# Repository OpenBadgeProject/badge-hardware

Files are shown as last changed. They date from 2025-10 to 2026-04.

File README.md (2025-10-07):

# Open Badge Project - Surface Mount Version

This is the Open Badge Project hardware repository.

There are two badge designs in this repo. The surface-mount directory holds the surface mount badge design. The production subdirectory contains the BOM and position data files.

The through-hole directory is for the through hole badge material. There is no BOM or pick and place spreadsheet. There's no reason you couldn't do that, but it was designed for humans to solder.

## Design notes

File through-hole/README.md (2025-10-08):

# Through Hole Badge design files

The programmer directory has a 3d model for a programmer that uses pogo pins connected to an arduino for programming

## Parts List
You can generate a bill of materials from KiCad, but for the sake of simplicity here is a list of all the parts.

- 1 [ATTINY85](https://www.digikey.com/en/products/detail/microchip-technology/ATTINY85-20PU/735469)
- 1 PCB (you have to get this made, you can't buy them)
- 2 [CD74HC595E](https://www.digikey.com/en/products/detail/texas-instruments/CD74HC595E/1507396) shift registers
- 1 [CD4021BE](https://www.digikey.com/en/products/detail/texas-instruments/CD4021BE/67261) shift register
- 1 [2032 battery holder](https://www.digikey.com/en/products/detail/adam-tech/BH-25C-1/13537703)
- 8 [100 Ohm resistors](https://www.digikey.com/en/products/detail/stackpole-electronics-inc/CF14JT100R/1741261)
- 8 [100K Ohm resistors](https://www.digikey.com/en/products/detail/stackpole-electronics-inc/CF14JT10K0/1741265)
- 6 [Buttons](https://www.amazon.com/gp/product/B07VSNN9S2/ref=ppx_yo_dt_b_asin_title_o00_s00?ie=UTF8&th=1)
- 1 [8x8 LED Display](https://www.aliexpress.us/item/3256805713726832.html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)

There may be better places to purchase these things than these links. Please submit a PR if you find something better.

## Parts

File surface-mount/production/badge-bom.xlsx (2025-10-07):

Comment | Designator | Footprint | LCSC Part Number
 | BAT1 | Battery:BatteryHolder_MPD_BC2003_1x2032 | C964831
 | D29,D8,D15,D52,D61,D27,D35,D1,D4,D26,D60,D3,D63,D20,D48,D10,D11,D49,D58,D40,D34,D17,D31,D36,D23,D2,D38,D24,D54,D57,D28,D42,D64,D55,D9,D16,D39,D53,D18,D19,D43,D62,D51,D56,D5,D33,D37,D50,D30,D13,D47,D41,D21,D22,D14,D59,D6,D12,D7,D46,D44,D32,D25,D45 | LED_SMD:LED_1206_3216Metric_Pad1.42x1.75mm_HandSolder | C84270
100 | R1,R3,R6,R5,R2,R7,R4,R8 | PCM_JLCPCB:R_0805 | C702858
10K | R15,R14,R11,R9,R10,R16,R13,R12 | PCM_JLCPCB:R_0805 | C17414
 | S1,S2,S3,S4,S5,S6 | Badge-Library:C83206,Button_Switch_SMD:SW_MEC_5GSH9 | C83206
 | U1 | Package_SO:SOIC-8_5.3x5.3mm_P1.27mm | C615549
 | U2 | PCM_JLCPCB:SOIC-16_L9.9-W3.9-P1.27-LS6.0-BL | C134120
 | U4,U3 | PCM_JLCPCB:SOIC-16_L9.9-W3.9-P1.27-LS6.0-BL | C5947

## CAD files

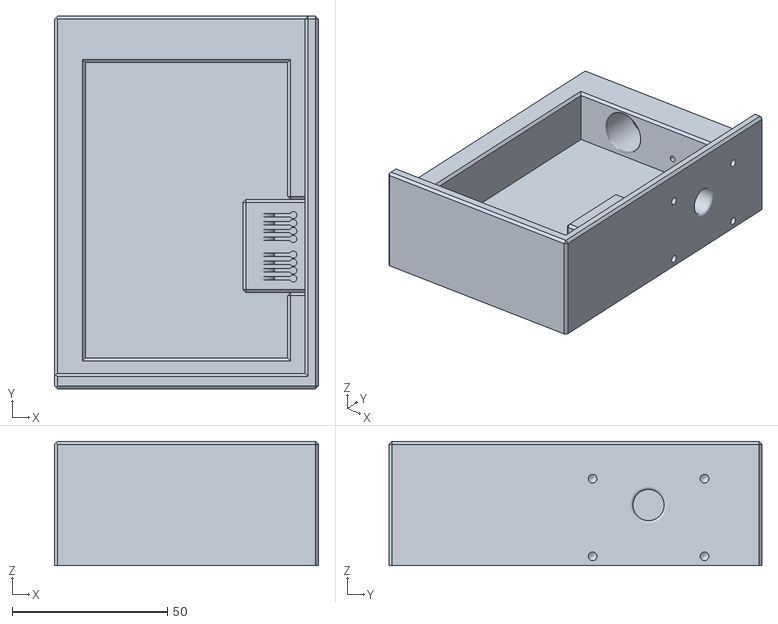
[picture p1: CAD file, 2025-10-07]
surface-mount/programmer/surface-mount-programmer.stl
85.0 x 120.0 x 40.0

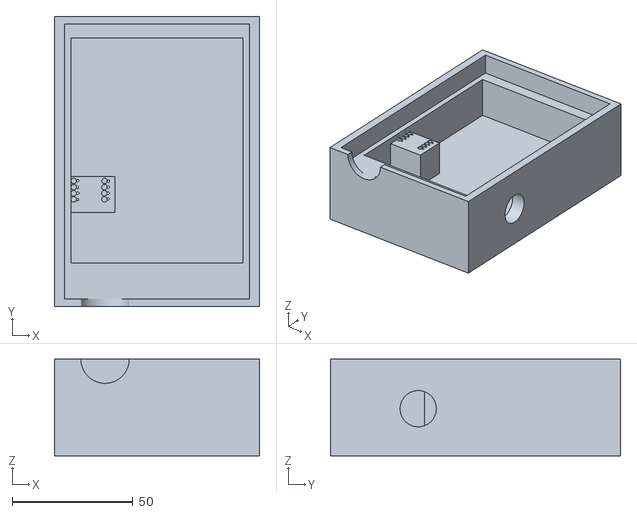
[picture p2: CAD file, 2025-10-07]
through-hole/programmer/through-hole-programmer.stl
85.0 x 120.0 x 40.0

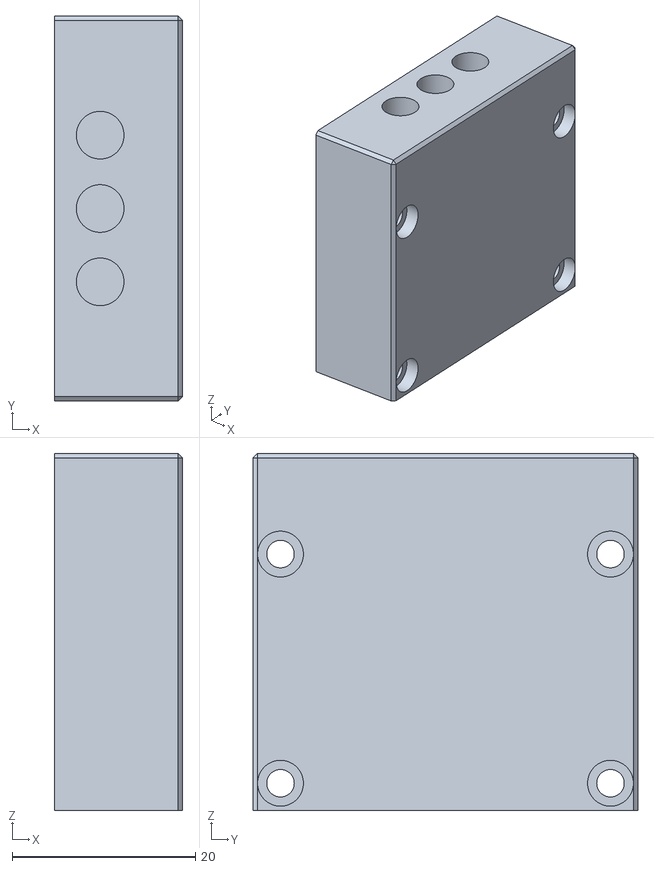
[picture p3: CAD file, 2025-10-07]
surface-mount/programmer/LED-holder.stl
14.0 x 42.0 x 39.0

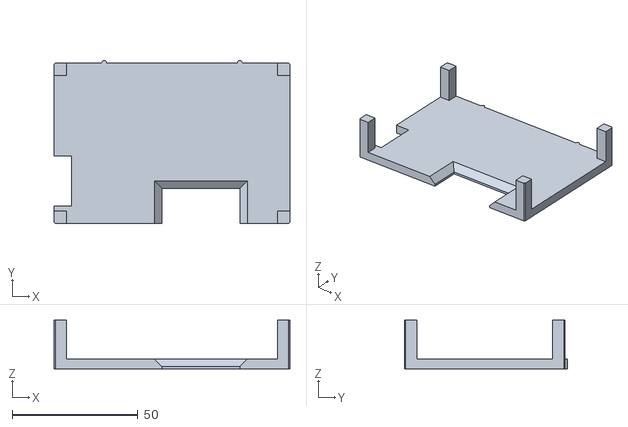
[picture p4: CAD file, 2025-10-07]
surface-mount/programmer/lid.stl
94.0 x 65.0 x 19.5

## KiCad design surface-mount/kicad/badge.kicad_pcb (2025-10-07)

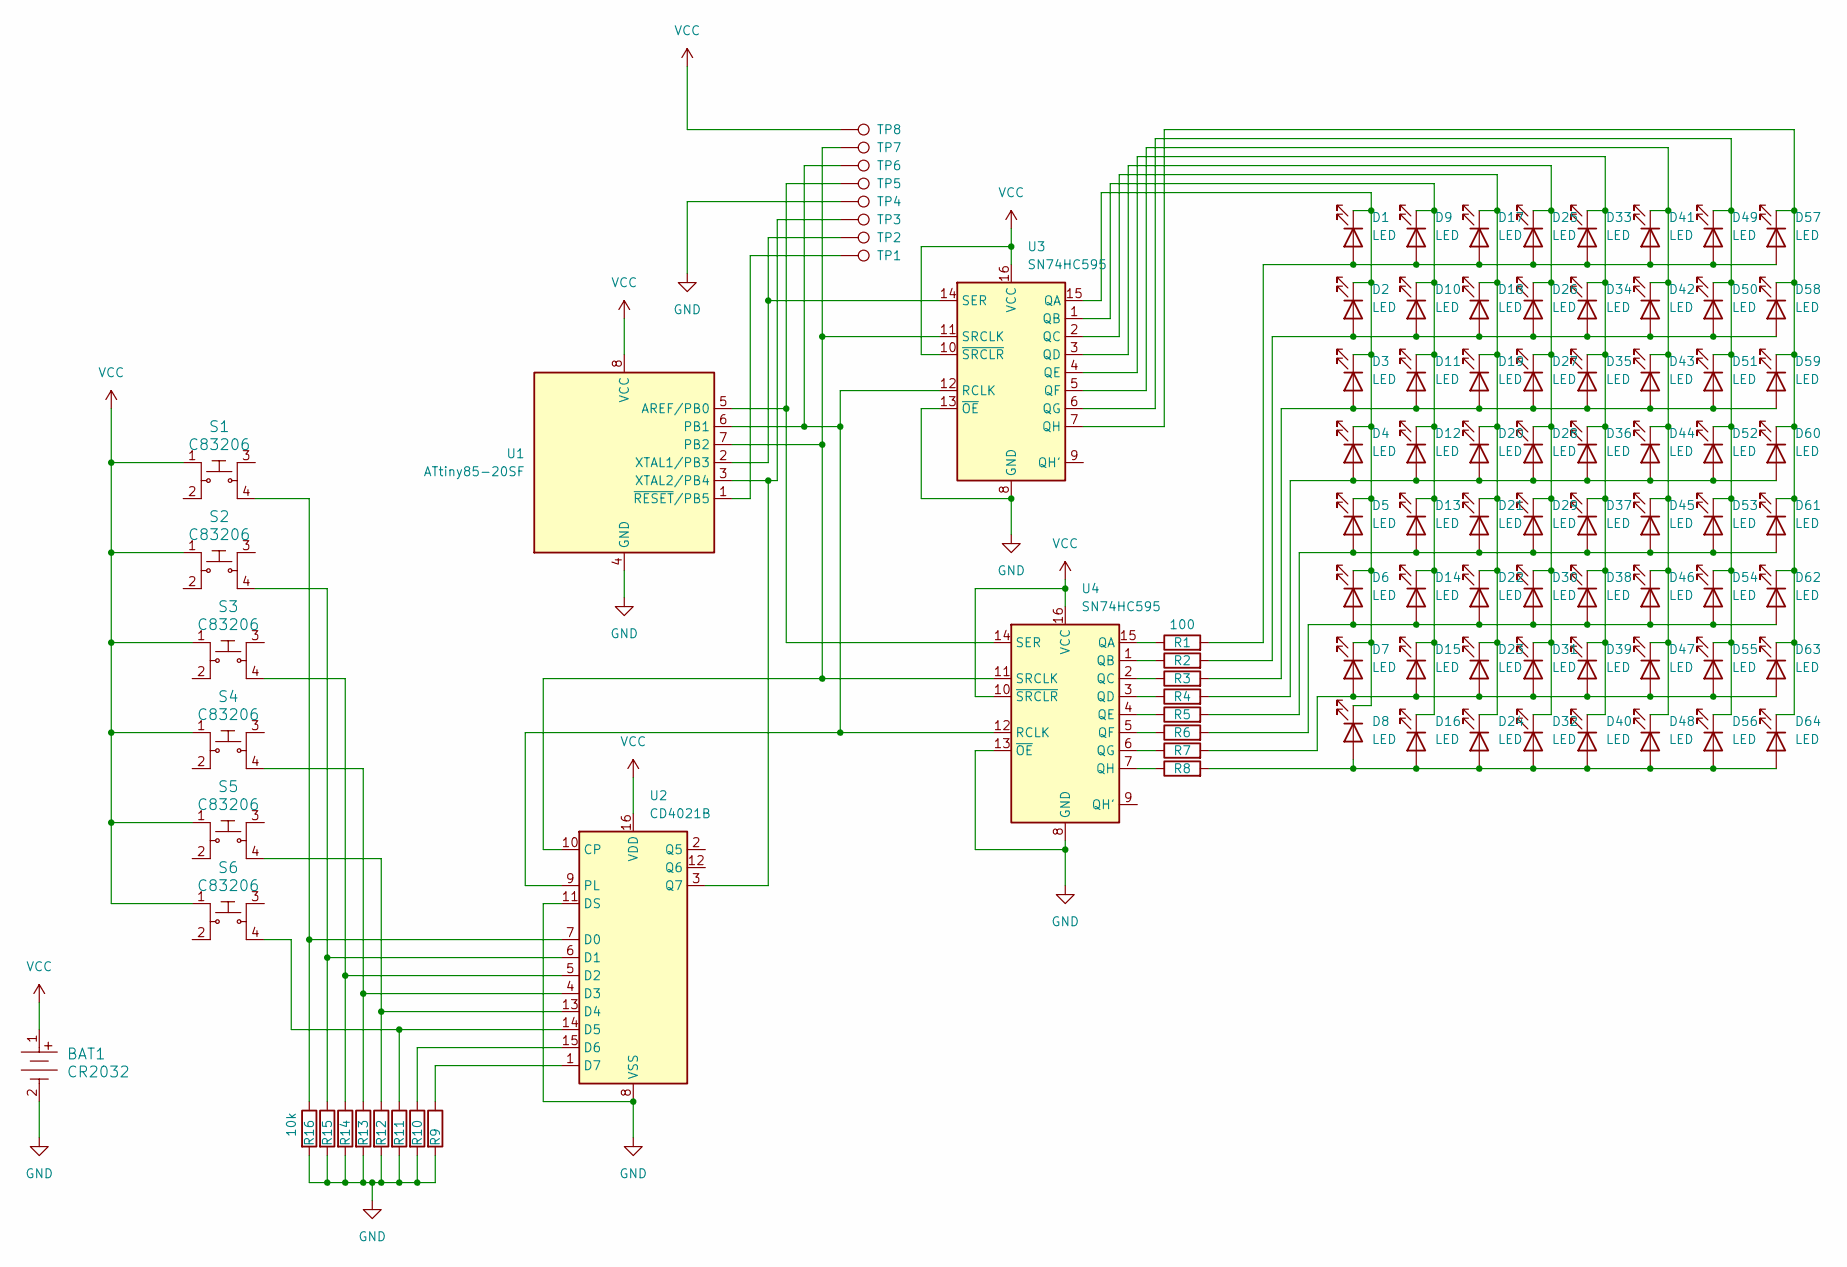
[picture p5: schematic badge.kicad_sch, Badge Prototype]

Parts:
BAT1: CR2032; BatteryHolder_MPD_BC2003_1x2032; MPN BS-7; JLCPCB Part # C964831
D1, D2, D3, D4, D5, D6, D7, D8, D9, D10, D11, D12, D13, D14, D15, D16, D17, D18, D19, D20, D21, D22, D23, D24, D25, D26, D27, D28, D29, D30, D31, D32, D33, D34, D35, D36, D37, D38, D39, D40, D41, D42, D43, D44, D45, D46, D47, D48, D49, D50, D51, D52, D53, D54, D55, D56, D57, D58, D59, D60, D61, D62, D63, D64: LED; LED_1206_3216Metric_Pad1.42x1.75mm_HandSolder
R1, R2, R3, R4, R5, R6, R7, R8: 100; R_0805
R9, R10, R11, R12, R13, R14, R15, R16: 10k; R_0805
S1: C83206; SW_MEC_5GSH9
S2, S3, S4, S5, S6: C83206; MPN TL3315NF160Q; Digi-Key_PN EG4621CT-ND
TP1, TP2, TP3, TP4, TP5, TP6, TP7, TP8: TestPoint; TestPoint_THTPad_D1.5mm_Drill0.7mm
U1: ATtiny85-20SF; SOIC-8_5.3x5.3mm_P1.27mm; JLCPCB Part # C615549
U2: CD4021B; SOIC-16_L9.9-W3.9-P1.27-LS6.0-BL; JLCPCB Part # C6729
U3, U4: SN74HC595; SOIC-16_L9.9-W3.9-P1.27-LS6.0-BL; JLCPCB Part # C5947

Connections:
GND: BAT1.2, R9.2, R10.2, R11.2, R12.2, R13.2, R14.2, R15.2, R16.2, TP4.1, U1.4 (GND), U2.8 (VSS), U2.11 (DS), U3.8 (GND), U3.13 (~OE), U4.8 (GND), U4.13 (~OE)
unnamed: D1.2 (A), D9.2 (A), D17.2 (A), D25.2 (A), D33.2 (A), D41.2 (A), D49.2 (A), D57.2 (A), R1.2
unnamed: D1.1 (K), D2.1 (K), D3.1 (K), D4.1 (K), D5.1 (K), D6.1 (K), D7.1 (K), D8.1 (K), U3.15 (QA)
unnamed: D2.2 (A), D10.2 (A), D18.2 (A), D26.2 (A), D34.2 (A), D42.2 (A), D50.2 (A), D58.2 (A), R2.2
unnamed: D9.1 (K), D10.1 (K), D11.1 (K), D12.1 (K), D13.1 (K), D14.1 (K), D15.1 (K), D16.1 (K), U3.1 (QB)
unnamed: D3.2 (A), D11.2 (A), D19.2 (A), D27.2 (A), D35.2 (A), D43.2 (A), D51.2 (A), D59.2 (A), R3.2
unnamed: D4.2 (A), D12.2 (A), D20.2 (A), D28.2 (A), D36.2 (A), D44.2 (A), D52.2 (A), D60.2 (A), R4.2
unnamed: D5.2 (A), D13.2 (A), D21.2 (A), D29.2 (A), D37.2 (A), D45.2 (A), D53.2 (A), D61.2 (A), R5.2
unnamed: D6.2 (A), D14.2 (A), D22.2 (A), D30.2 (A), D38.2 (A), D46.2 (A), D54.2 (A), D62.2 (A), R6.2
unnamed: D7.2 (A), D15.2 (A), D23.2 (A), D31.2 (A), D39.2 (A), D47.2 (A), D55.2 (A), D63.2 (A), R7.2
unnamed: D8.2 (A), D16.2 (A), D24.2 (A), D32.2 (A), D40.2 (A), D48.2 (A), D56.2 (A), D64.2 (A), R8.2
unnamed: D17.1 (K), D18.1 (K), D19.1 (K), D20.1 (K), D21.1 (K), D22.1 (K), D23.1 (K), D24.1 (K), U3.2 (QC)
unnamed: D25.1 (K), D26.1 (K), D27.1 (K), D28.1 (K), D29.1 (K), D30.1 (K), D31.1 (K), D32.1 (K), U3.3 (QD)
unnamed: D33.1 (K), D34.1 (K), D35.1 (K), D36.1 (K), D37.1 (K), D38.1 (K), D39.1 (K), D40.1 (K), U3.4 (QE)
unnamed: D41.1 (K), D42.1 (K), D43.1 (K), D44.1 (K), D45.1 (K), D46.1 (K), D47.1 (K), D48.1 (K), U3.5 (QF)
unnamed: D49.1 (K), D50.1 (K), D51.1 (K), D52.1 (K), D53.1 (K), D54.1 (K), D55.1 (K), D56.1 (K), U3.6 (QG)
unnamed: D57.1 (K), D58.1 (K), D59.1 (K), D60.1 (K), D61.1 (K), D62.1 (K), D63.1 (K), D64.1 (K), U3.7 (QH)
unnamed: TP5.1, U1.5 (AREF/PB0), U4.14 (SER)
unnamed: TP6.1, U1.6 (PB1), U2.9 (PL), U3.12 (RCLK), U4.12 (RCLK)
unnamed: TP7.1, U1.7 (PB2), U2.10 (CP), U3.11 (SRCLK), U4.11 (SRCLK)
unnamed: TP2.1, U1.2 (XTAL1/PB3), U3.14 (SER)
unnamed: TP3.1, U1.3 (XTAL2/PB4), U2.3 (Q7)
unnamed: TP1.1, U1.1 (~RESET/PB5)
unnamed: R16.1, S1.4, U2.7 (D0)
unnamed: R15.1, S2.4, U2.6 (D1)
unnamed: R14.1, S3.4, U2.5 (D2)
unnamed: R13.1, S4.4, U2.4 (D3)
unnamed: R12.1, S5.4, U2.13 (D4)
unnamed: R11.1, S6.4, U2.14 (D5)
unnamed: R10.1, U2.15 (D6)
unnamed: R9.1, U2.1 (D7)
unnamed: R1.1, U4.15 (QA)
unnamed: R2.1, U4.1 (QB)
unnamed: R3.1, U4.2 (QC)
unnamed: R4.1, U4.3 (QD)
unnamed: R5.1, U4.4 (QE)
unnamed: R6.1, U4.5 (QF)
unnamed: R7.1, U4.6 (QG)
unnamed: R8.1, U4.7 (QH)
VCC: BAT1.1, S1.1, S2.1, S3.1, S4.1, S5.1, S6.1, TP8.1, U1.8 (VCC), U2.16 (VDD), U3.10 (~SRCLR), U3.16 (VCC), U4.10 (~SRCLR), U4.16 (VCC)

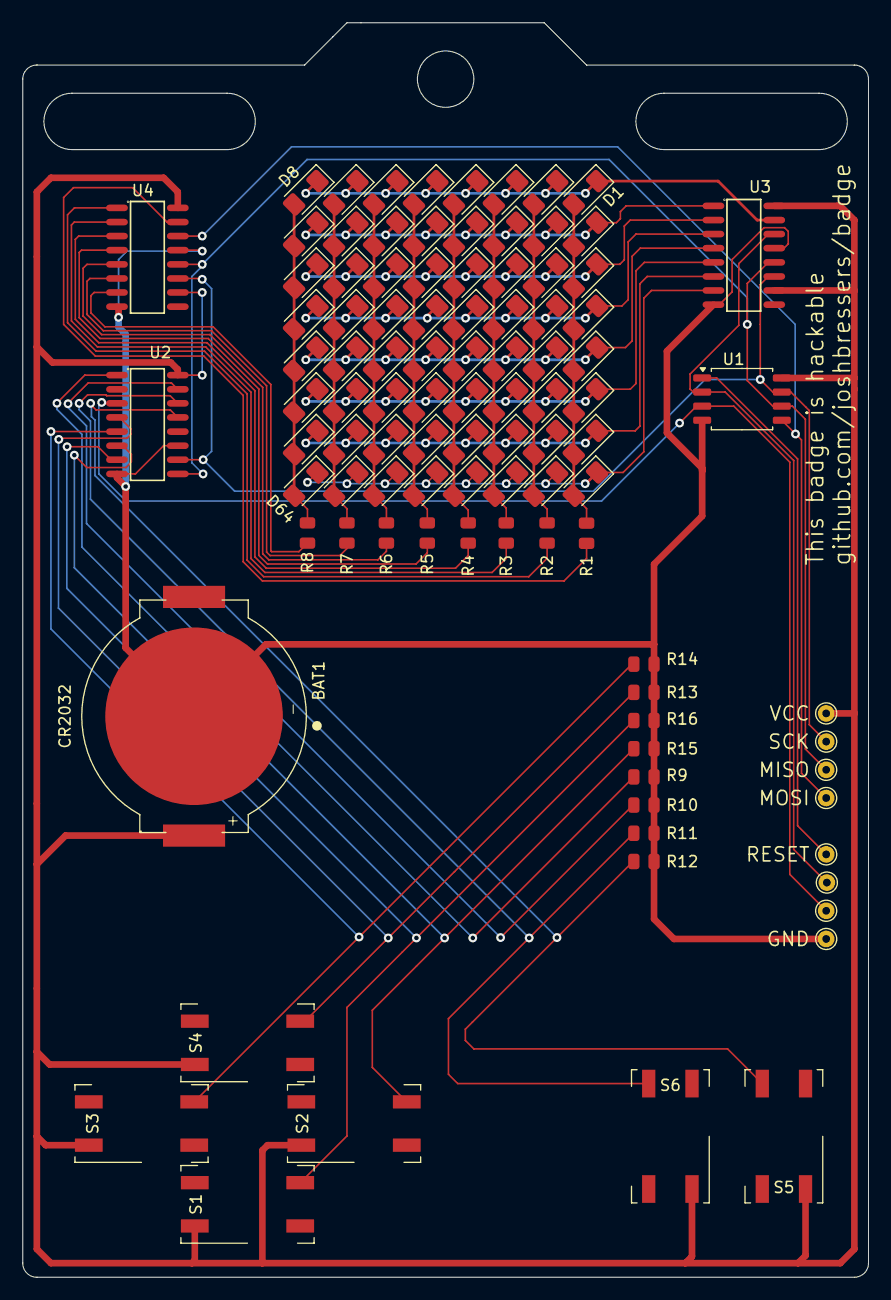
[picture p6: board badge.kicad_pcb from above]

Board: 2 copper layers, 76.2 x 113.0 mm, 99 parts (0 on the bottom side), 40 nets.

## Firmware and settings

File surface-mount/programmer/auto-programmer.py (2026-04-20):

# SPDX-FileCopyrightText: 2021 ladyada for Adafruit Industries
# SPDX-License-Identifier: MIT

"""
ATtiny13a programming example, be sure you have the '13a wired up so:
  ATtiny13a GND to CircuitPython GND
  ATtiny13a VCC to CircuitPython USB
  Pin 2 -> CircuitPython SCK
  Pin 1 -> CircuitPython MISO
  Pin 0 -> CircuitPython MOSI
  RESET  -> CircuitPython D5 (or change the init() below to change it!)
Drag "attiny13a_blink.hex" onto the CircuitPython disk drive, then open REPL!
"""

import sys
import time
import board
import busio
import microcontroller
import microcontroller.pin
import digitalio

import adafruit_avrprog

#sck = microcontroller.pin.GPIO18
#mosi = microcontroller.pin.GPIO19
#miso = microcontroller.pin.GPIO16

sck = microcontroller.pin.GPIO18
mosi = microcontroller.pin.GPIO19
miso = microcontroller.pin.GPIO16
reset = microcontroller.pin.GPIO10

spi = busio.SPI(sck, mosi, miso)
avrprog = adafruit_avrprog.AVRprog()
avrprog.init(spi, reset)
# Each chip has to have a definition so the script knows how to find it
attiny85 = avrprog.Boards.ATtiny85

switch = digitalio.DigitalInOut(board.GP0)
switch.switch_to_input(pull=digitalio.Pull.UP)

redLight = digitalio.DigitalInOut(board.GP8)
redLight.direction = digitalio.Direction.OUTPUT
yelLight = digitalio.DigitalInOut(board.GP7)
yelLight.direction = digitalio.Direction.OUTPUT
grnLight = digitalio.DigitalInOut(board.GP9)
grnLight.direction = digitalio.Direction.OUTPUT

grnLight.value = True
yelLight.value = False
redLight.value = False

def error(err):
    """Helper to print out errors for us and then halt"""
    print("ERROR: " + err)
    avrprog.end()

    grnLight.value = False
    yelLight.value = False
    redLight.value = True
    
    raise Exception(err)


# Main
while True:

    end_state = None

    # False is pressed
    if switch.value != False:
        time.sleep(0.5)
        continue

    time.sleep(1) # Debounce

    grnLight.value = False
    yelLight.value = True
    redLight.value = False
    try:
        
        if not avrprog.verify_sig(attiny85, verbose=True):
            error("Signature read failure")

        print("Found", attiny85["name"])

        fuses = avrprog.read_fuses(attiny85)

        print("Fuses")
        print(fuses)

        avrprog.write_fuses(attiny85, low=0x62, high=0xD7, ext=0x07, lock=0x3F)

        print("Programming flash from file")

        if not avrprog.program_file(attiny85, "badge.ino.hex", verbose=True, verify=True):
            error("Failure programming flash")
        avrprog.end()
    except Exception as e:
        print("Failure programming flash")
        print(e)
        avrprog.end()
        grnLight.value = False
        yelLight.value = False
        redLight.value = True
        end_state = False

    else:
        print("Done!")

        grnLight.value = True
        yelLight.value = False
        redLight.value = False
        end_state = True
    
    # wait for the switch to be opened
    while switch.value == False:
        time.sleep(0.5)
        if end_state == True:
            grnLight.value = not grnLight.value
        else:
            redLight.value = not redLight.value
        
    time.sleep(2) # This is our debouncer
    grnLight.value = True
    yelLight.value = False
    redLight.value = False
